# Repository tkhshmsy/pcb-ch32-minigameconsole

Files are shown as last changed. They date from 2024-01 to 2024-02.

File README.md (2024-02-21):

# PCB-ch32-minigameconsole

Private designed PCB for [CH32V003-GameConsole](https://github.com/wagiminator/CH32V003-GameConsole)

## Features
* Size 45 x 48 mm
  * Panelized 4 pcs in 100 x 100mm
* Using THT parts except CH32V003
  * All parts are able to purchase from [Akizuki-Denshi](https://akizukidenshi.com/)

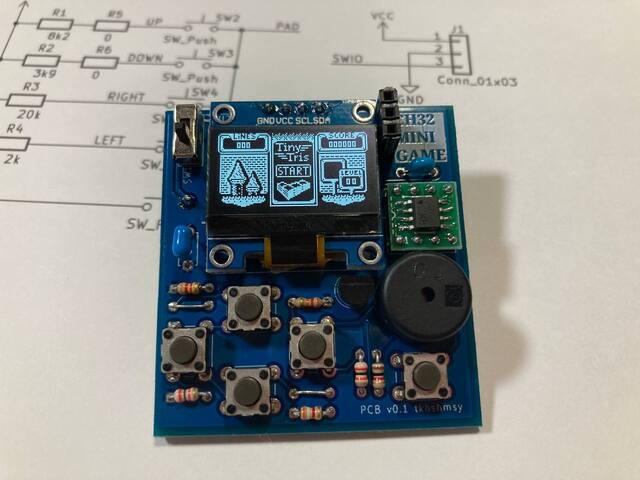
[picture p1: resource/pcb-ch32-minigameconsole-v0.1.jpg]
board


## Schematic and Layout

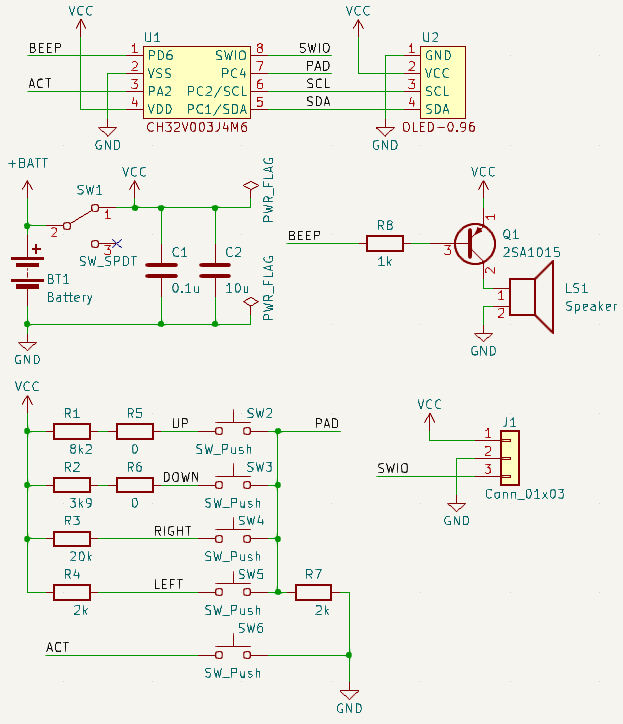
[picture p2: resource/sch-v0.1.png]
schematic

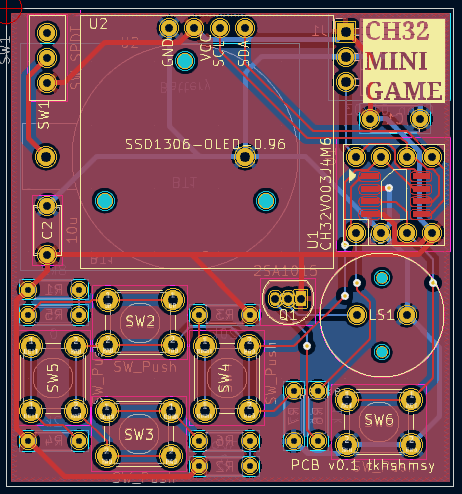
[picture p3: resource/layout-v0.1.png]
layout


## BOM
|Ref|Name|Qty|Description|Link|
|---|----|---|---|----|
|U1|CH32V003J4M6|1||https://akizukidenshi.com/catalog/g/g118062/|
|U1 ext|SOP8 to DIP8 conversion board|1||https://akizukidenshi.com/catalog/g/g105154|
|U2|OLED 0.96inch|1|128x64 monochrome, i2c|https://akizukidenshi.com/catalog/g/g112031/|
|BT1|CR2032 holder|1||https://akizukidenshi.com/catalog/g/g100706/|
|Q1|2SA1015|1||https://akizukidenshi.com/catalog/g/g117091/|
|LS1|Sounder/Speaker|1||https://akizukidenshi.com/catalog/g/g104118/|
|C1|Capacitor 0.1uF|1||https://akizukidenshi.com/catalog/g/g115927/|
|C2|Capacitor 10uF|1||https://akizukidenshi.com/catalog/g/g103095/|
|R1|Resist 8k2|1||https://akizukidenshi.com/catalog/g/g116822/|
|R2|Resist 3k9|1||https://akizukidenshi.com/catalog/g/g116392/|
|R3|Resist 20k|1|for test build, use 22k|https://akizukidenshi.com/catalog/g/g107842/ or https://akizukidenshi.com/catalog/g/g116223/|
|R4, R7|Resist 2k|2||https://akizukidenshi.com/catalog/g/g116202/|
|R5, R6|Resist 0|2|These are 'Dummy' to create resistance value of R1 / R2 in combination. See 'Other set of resistors'||
|R8|Resist 1k|1|see Errata|https://akizukidenshi.com/catalog/g/g116102/|
|SW1|Slide switch|1||https://akizukidenshi.com/catalog/g/g115707/|
|SW2-6|Push switch|5||https://akizukidenshi.com/catalog/g/g103647/|
|J1|3 pins header/socket|1|SWD port|https://akizukidenshi.com/catalog/g/g115510/ or https://akizukidenshi.com/catalog/g/g110098/|
|--|WCH-LinkE emulator|1|SWD/JTAG tool|https://akizukidenshi.com/catalog/g/g118065/|

### Other set of resistors

|Ref|Set 1(Original)|Set 2|
|---|---|-----|
|R1|8k2|4k7|
|R2|3k9|2k2|
|R3|20k|22k|
|R4|2k|2k2|
|R5|0|4k7|
|R6|0|2k2|
|R7|2k|2k2|
|R8|1k|100|

## Errata
* v0.1
  * Sometimes, The LEFT button (SW5) acts as the RIGHT button.
    * It seems to be due to poor analog wiring.
  * Sound too small
    * It seems the limiting resist (R8=1k) is too large.

## How to run
on Linux,

1. Prepare
   1. Get [WCH-LinkE](https://akizukidenshi.com/catalog/g/g118065/)
   2. Download original repository https://github.com/wagiminator/CH32V003-GameConsole
      1. use *.bin files.
   3. Download repository https://github.com/cnlohr/ch32v003fun
      1. use the tool 'minichlink' to write firmware.
2. Write firmware
   1. Build 'minichlink'
   2. Connect WCH-LinkE to PC and PCB with pushing 'ModeS' button.
      1. ref: https://github.com/cnlohr/ch32v003fun/issues/227
      2. to PCB side, connect '3V3, 'GND' and 'SWDIO' to J1.
   3. Write firmware
        ```bash
        ## e.g. tiny-tris
        $ ./minichlink -w CH32V003-GameConsole/software/tiny_tris/tiny_tris.bin flash -b
        ```
3. Enjoy !

## License
Original codes are licensed under Creative Commons.
* Creative Commons Attribution-ShareAlike 3.0 Unported License. (http://creativecommons.org/licenses/by-sa/3.0/)

This PCB project is licensed under same Creative Commons too.



## Author
* tkhshmsy@gmail.com

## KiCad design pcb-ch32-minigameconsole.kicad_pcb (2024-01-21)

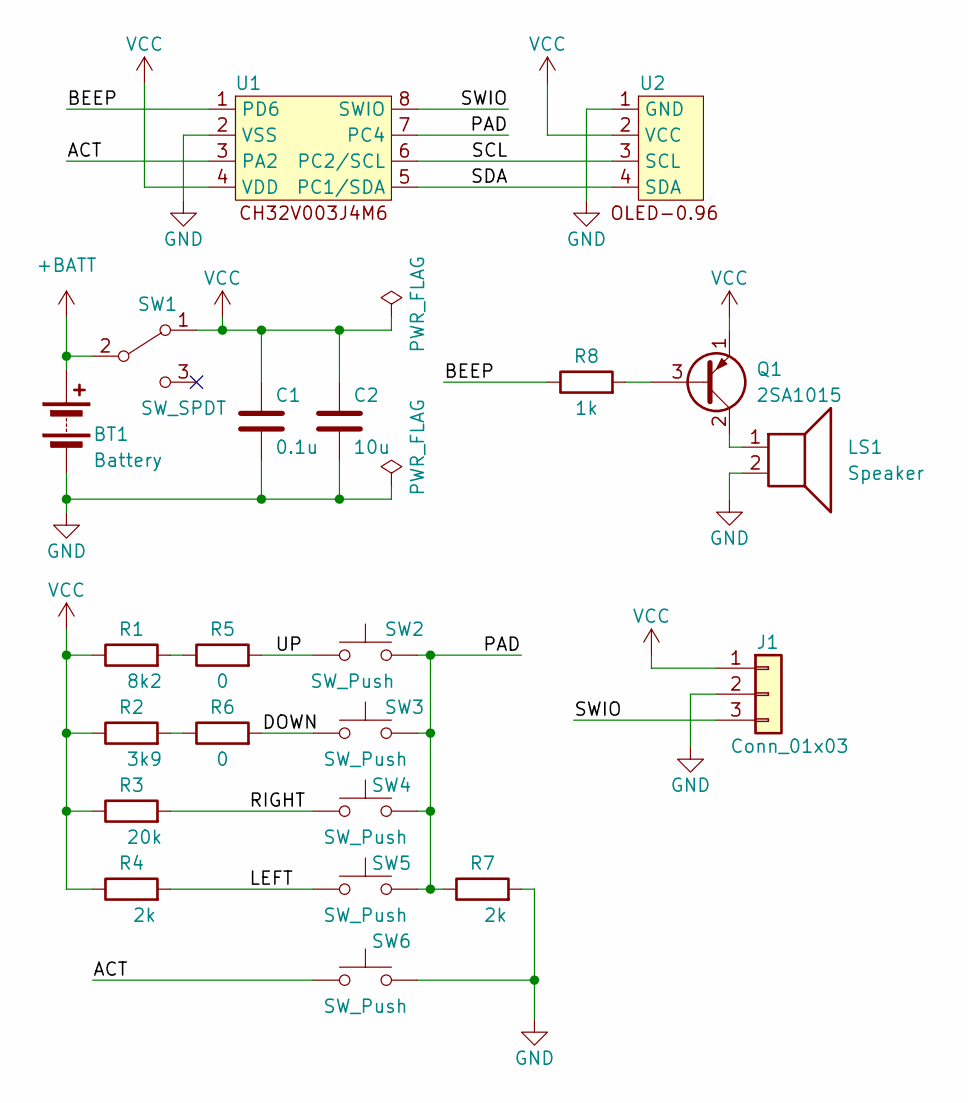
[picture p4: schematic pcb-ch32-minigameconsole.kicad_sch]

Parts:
BT1: Battery; CH25-2032LF
C1: 0.1u; C_Disc_D4.7mm_W2.5mm_P5.00mm
C2: 10u; C_Disc_D4.7mm_W2.5mm_P5.00mm
J1: Conn_01x03; PinSocket_1x03_P2.54mm_Horizontal
LS1: Speaker; PKM13EPYH4000-A0
Q1: 2SA1015; TO-92_Inline
R1: 8k2; R_Axial_DIN0204_L3.6mm_D1.6mm_P5.08mm_Horizontal
R2: 3k9; R_Axial_DIN0204_L3.6mm_D1.6mm_P5.08mm_Horizontal
R3: 20k; R_Axial_DIN0204_L3.6mm_D1.6mm_P5.08mm_Horizontal
R4, R7: 2k; R_Axial_DIN0204_L3.6mm_D1.6mm_P5.08mm_Horizontal
R5, R6: 0; R_Axial_DIN0204_L3.6mm_D1.6mm_P5.08mm_Horizontal
R8: 1k; R_Axial_DIN0204_L3.6mm_D1.6mm_P5.08mm_Horizontal
SW1: SW_SPDT; SS-12D00G3
SW2, SW3, SW4, SW5, SW6: SW_Push; SW_PUSH_6mm_H7.3mm
U1: CH32V003J4M6-Dual
U2: OLED-0.96

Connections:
+BATT: BT1.1 (+), SW1.2 (B)
/ACT: SW6.1, U1.3 (PA2)
/BEEP: R8.1, U1.1 (PD6)
/DOWN: R6.2, SW3.1
/LEFT: R4.2, SW5.1
/PAD: R7.1, SW2.2, SW3.2, SW4.2, SW5.2, U1.7 (PC4)
/RIGHT: R3.2, SW4.1
/SCL: U1.6 (PC2/SCL), U2.3 (SCL)
/SDA: U1.5 (PC1/SDA), U2.4 (SDA)
/SWIO: J1.3, U1.8 (SWIO)
/UP: R5.2, SW2.1
GND: BT1.2 (-), C1.2, C2.2, J1.2, LS1.2, R7.2, SW6.2, U1.2 (VSS), U2.1 (GND)
unnamed: Q1.3 (B), R8.2
unnamed: LS1.1, Q1.2 (C)
unnamed: R1.2, R5.1
unnamed: R2.2, R6.1
VCC: C1.1, C2.1, J1.1, Q1.1 (E), R1.1, R2.1, R3.1, R4.1, SW1.1 (A), U1.4 (VDD), U2.2 (VCC)

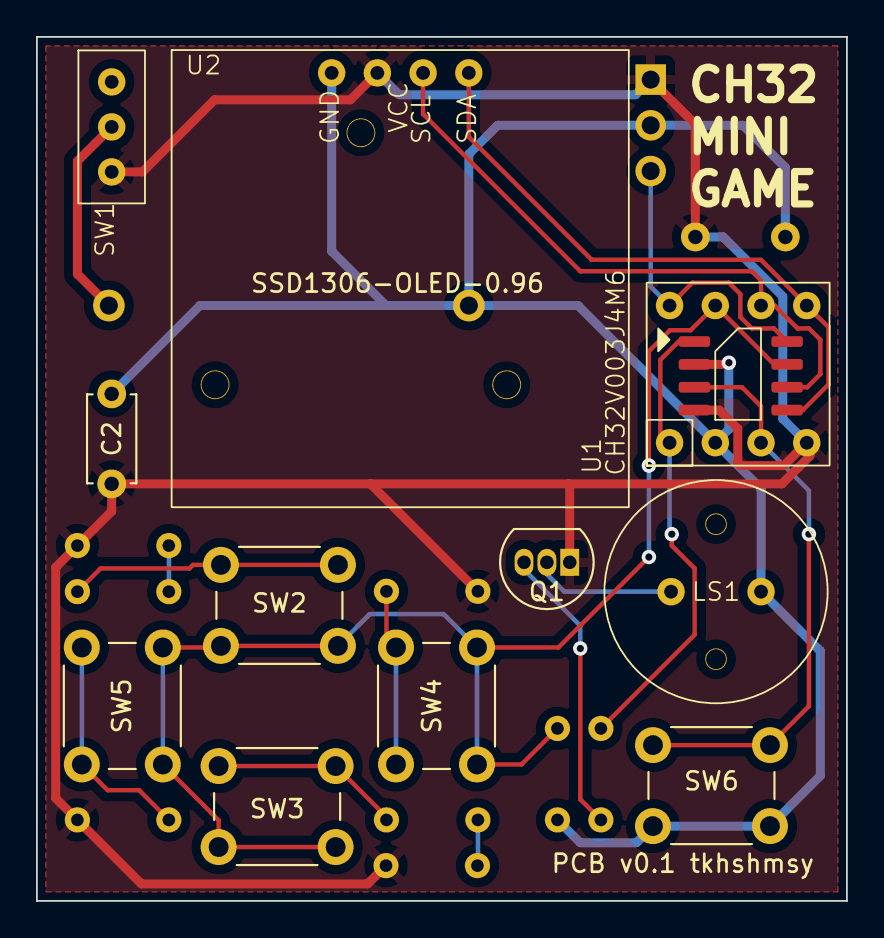
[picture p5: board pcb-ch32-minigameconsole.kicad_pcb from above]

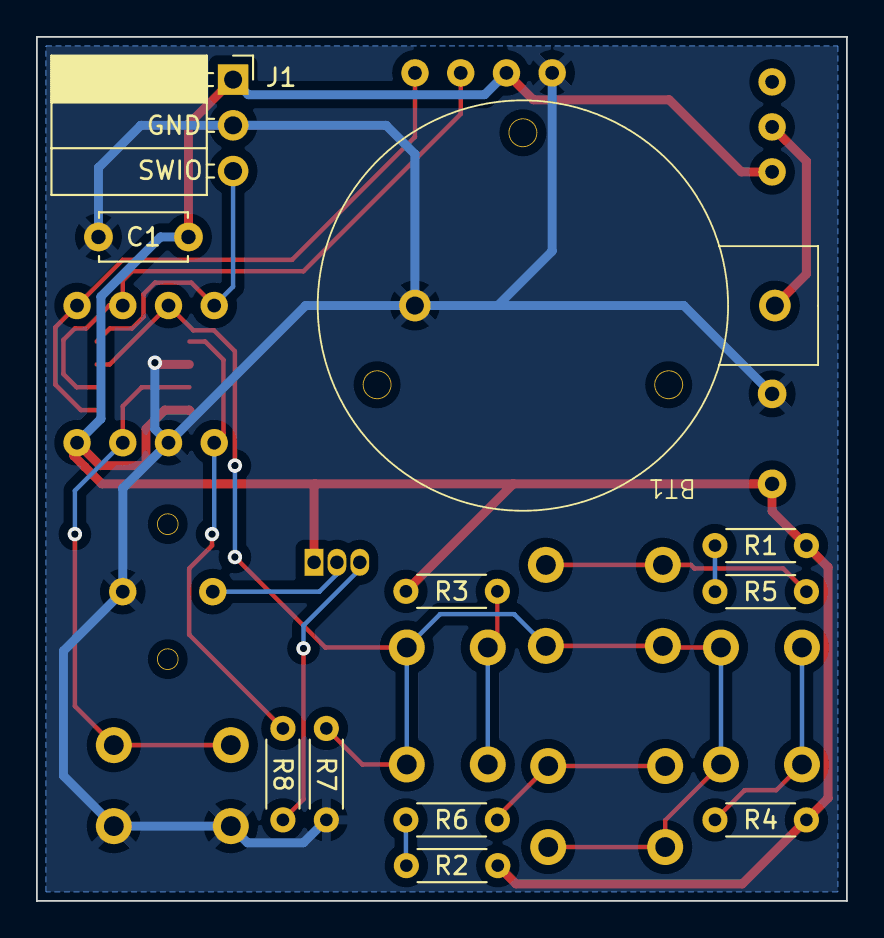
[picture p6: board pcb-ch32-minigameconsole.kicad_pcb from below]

Board: 2 copper layers, 45.0 x 48.0 mm, 22 parts (11 on the bottom side), 17 nets.
